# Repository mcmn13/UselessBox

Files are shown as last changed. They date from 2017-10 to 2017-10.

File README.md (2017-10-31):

# UselessBox
Another Useless Box
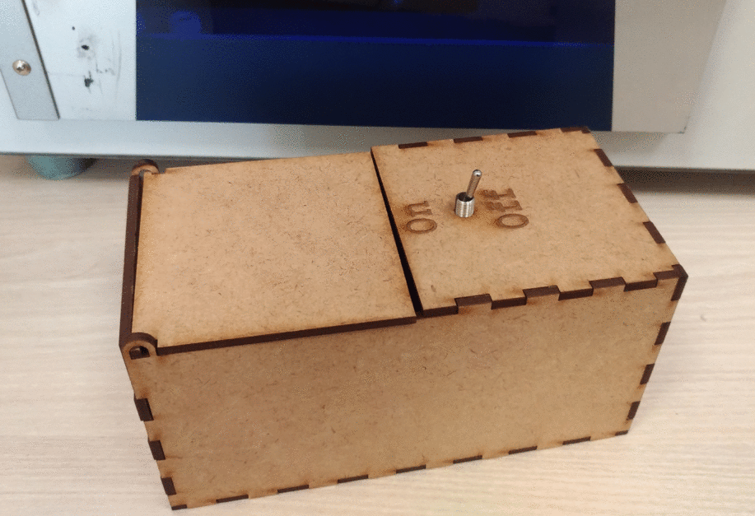
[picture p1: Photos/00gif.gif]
Useless Box en action Useless Box en Action


---

Dans le cadre de notre stage, nous avions pour exercice de mettre en place un atelier de médiation numérique à base de bidouillage Arduino.
Mon choix s'est tourné vers la création d'une "Useless Box" [lien wikipédia](https://fr.wikipedia.org/wiki/Machine_inutile).
Lors de mes recherches, je n'ai pas été satisfait des trouvailles et ai donc mixé différentes sources/projets afin de créer une "Useless Box" compact et simpliste.
La boite est potentiellement améliorable (ajout d'un second servomoteur pour gérer l'ouverture de la trappe, ajout d'un jeu de lumière par LED, ajout de capteur de présence/radar et d'élément de déplacement, mise en place d'un code avec plusieurs scénarios, etc...)
Par manque de temps, je vous livre ici les plans et la documentation nécessaire à l'élaboration d'une useless box basique, libre à vous de lui ajouter d'autres fonctions ;)

PS : sur mon modèle de présentation, il n'y à pas d'interrupteur de mise sous-tension. Il faut alors débrancher/rebrancher manuellement le port VIN pour l'éteindre complétement et préserver la batterie.
N'oubliez pas d'éditer le fichier SVG pour y inclure une fente à la taille de votre interrupteur.

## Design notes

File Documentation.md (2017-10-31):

# Documentation : création d'une Useless Box 
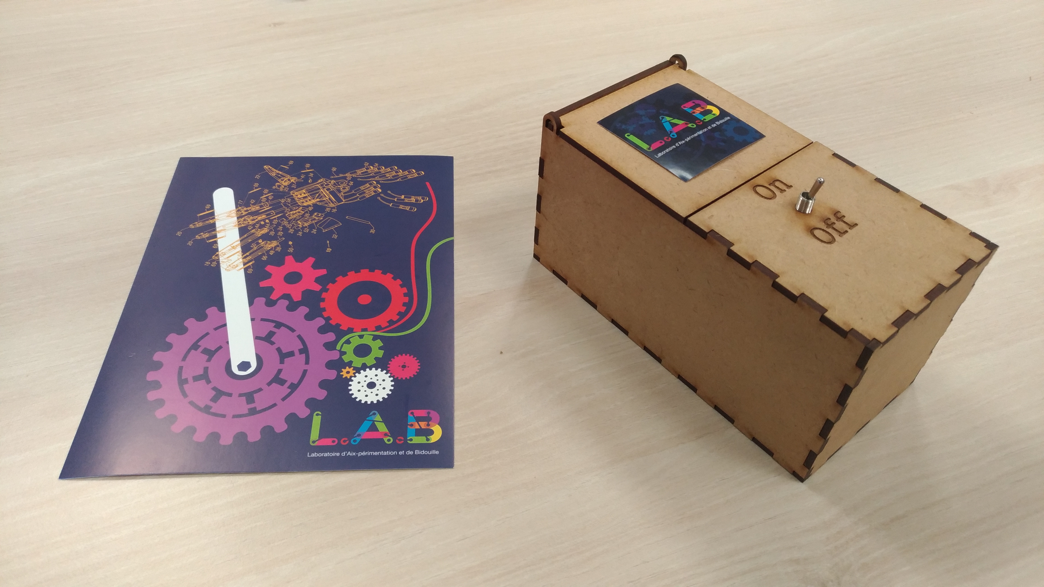
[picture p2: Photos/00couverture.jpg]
Useless Box

# Présentation et objectif pédagogique

Création d'une Useless Box en bois à base d'Arduino.

Objectif pédagogique : 	

- Découvrir les principes de l'électronique
- Savoir utiliser des outils d'électronique dans le respect des règles de sécurité
---

# Pré-requis
## Matériel (total de 42,83€)
- 1 Arduino Uno 21€ ([RS-Composant](http://fr.rs-online.com/web/p/kits-de-developpement-pour-processeurs-et-microcontroleurs/7697409/))
- 1 Servomoteur 12,27€ ([RS-Composant](http://fr.rs-online.com/web/p/servomoteurs/7813058/))
- 1 Bouton Toggle Switch 1,86€ ([RS-Composant](http://fr.rs-online.com/web/p/interrupteurs-a-levier/4480911/))
- 1 Résistance 320 omh
- 1 Connecteur 9V 1,68€ ([ebay](http://www.ebay.fr/itm/1-2-3-4-6-8-x-AA-AAA-23A-9V-Battery-Holder-Snap-On-Connector-Enclosed-Box-Switch/180814661762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))
- 6 Piles AAA 2,96€ les 12 ([RS-Composant](http://fr.rs-online.com/web/p/piles-aaa/7442209/))
- Fils électriques isolés 1,20€ les 65 ([ebay](http://www.ebay.fr/itm/65pcs-Male-to-Male-Flexible-Solderless-Breadboard-Jumper-Cable-Wires-For-Arduino/301227825820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))
- 1 autre bouton toggle switch pour faire la mise sous-tension 1,86€([RS-Composant](http://fr.rs-online.com/web/p/interrupteurs-a-levier/4480911/))
---

## Matériaux
- Planche de Bois 325x250x3mm
- Fil d'étain

## Outils
- Découpeuse laser
- Fer à souder
- Pistolet à colle
- Colle type super glue
- Cable USB PC/Arduino

## Logiciel
- Arduino
- Inkscape
- JobControl (découpeuse laser)

# Création d'une Useless Box

## Etape 1 : Préparation de la boite
1. Munissez-vous d'une plaque de bois 325x300mm d'épaisseur 3mm
2. Préparez la découpeuse laser puis, lancer la découpe à l'aide du fichier ([Plan de coupe](/Ressources/UselessBox_plan-modifié.svg/))
3. Assemblez et collez (super glue ou pistolet-à-colle) la base à ainsi que le côté bas et droit de la boite
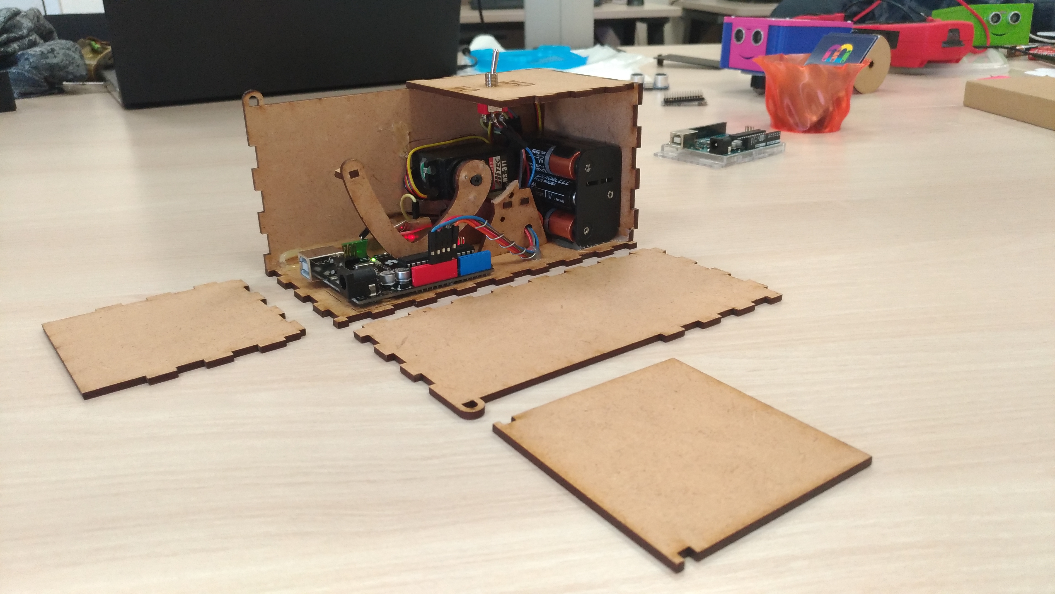
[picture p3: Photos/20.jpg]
Useless Box en assemblage

4. Ne collez pas le couvercle, nous le fixerons après avoir soudé l'interrupteur  :smile:

Nous allons maintenant passer au montage la partie éléctronique

---

## Etape 2 : Montage et préparation de l'Arduino
Référez vous au Fritzing "Useless Box"
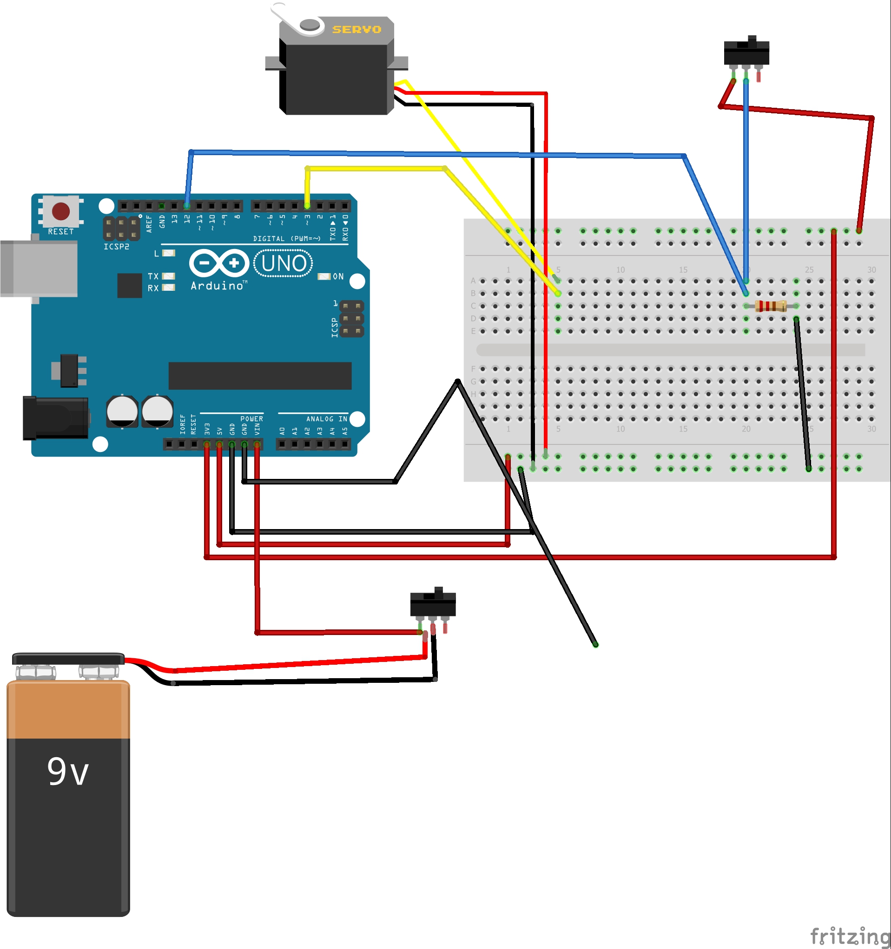
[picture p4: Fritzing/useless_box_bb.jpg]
Fritzing


Les composants à souder : 	
- Connecteur 9V
- Servomoteur
- Résistance
- Boutons toggle switch

**N'oubliez pas de téléverser et tester votre circuit avant de passer à l'assemblage !**

---

## Etape 3 :Assemblage du circuit dans la boite

- Placez l'interrupteur à son emplacement prévu sur la boite.
- Vérifiez le sens "on-off" de l'interrupteur ; Le servomoteur doit s'activer de l'activation (off) jusqu'à la désactivation (off)
- Une fois le sens du bouton toggle switch vérifié, fixez-le à l'aide de super glue
- Avec le pistolet-à-colle, fixez l'adaptateur 9V. N'oubliez pas d'inclure les piles !
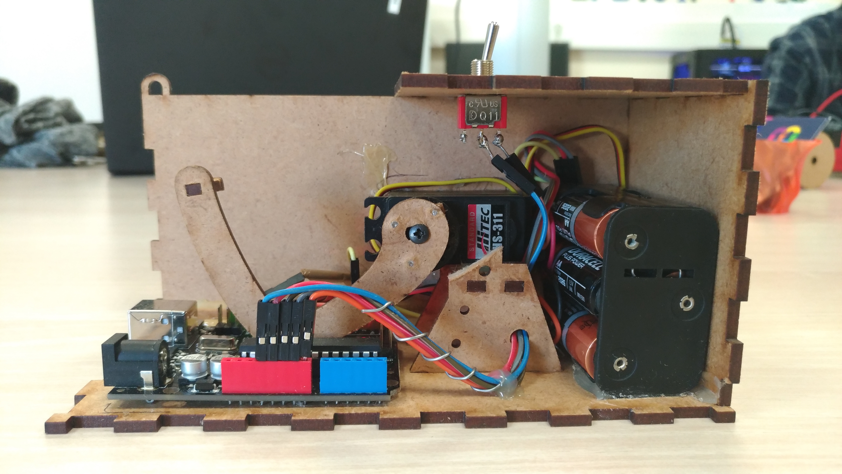
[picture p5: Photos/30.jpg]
Vue de face

- Pour positionner correction le servomoteur, faite un essai avant de le fixer
- Fixez le "Finger" (partie en bois qui vient appuyer l'interrupteur) sur le servomoteur
- Fixez le support en bois sur la base de la boite à l'aide de super glue
- Fixez le servomoteur en le collant sur son support et contre la paroi
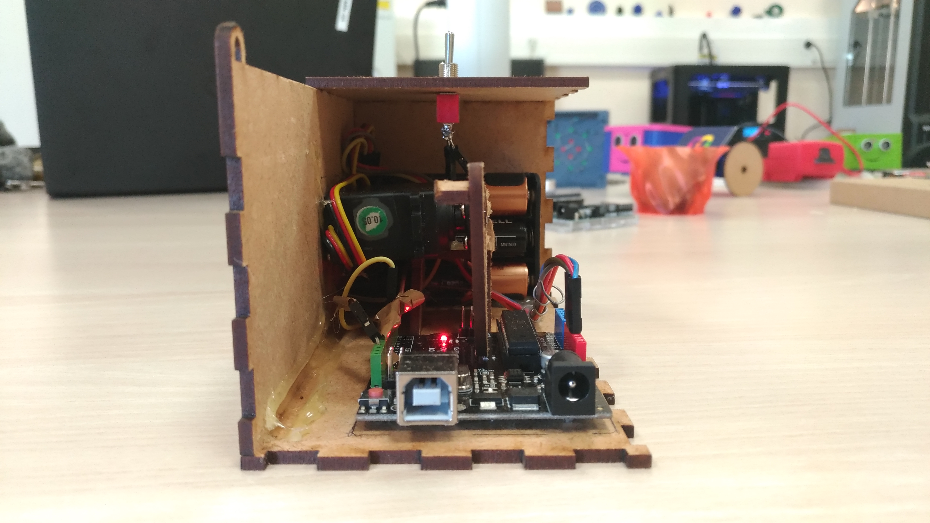
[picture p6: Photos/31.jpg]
Vue de côté

- Fixez l'Arduino sur la base de la carte à l'aide du pistolet-à-colle
- Insérez et fixez l'interrupteur de mise sous-tension à son emplacement prévu (tranche de la boite)
- Fixez le couvercle contenant l'interrupteur à la boite

Je vous conseil de ne pas fixer les 2 autres côtés : l'un permettant l'accès aux piles pour un changement, l'autre permettant l'accès au port USB de l'Arduino.

---
# Pour aller plus loin

N'hésitez pas à rajouter une LED, un second servomoteur, améliorer le code (mise en place de scénario), un capteur de proximité, des roues, etc...

---
# Bibliographie
[Plan de coupe initiale par le FabLab de Leuven](https://fablab-leuven.be/?q=node/1648)

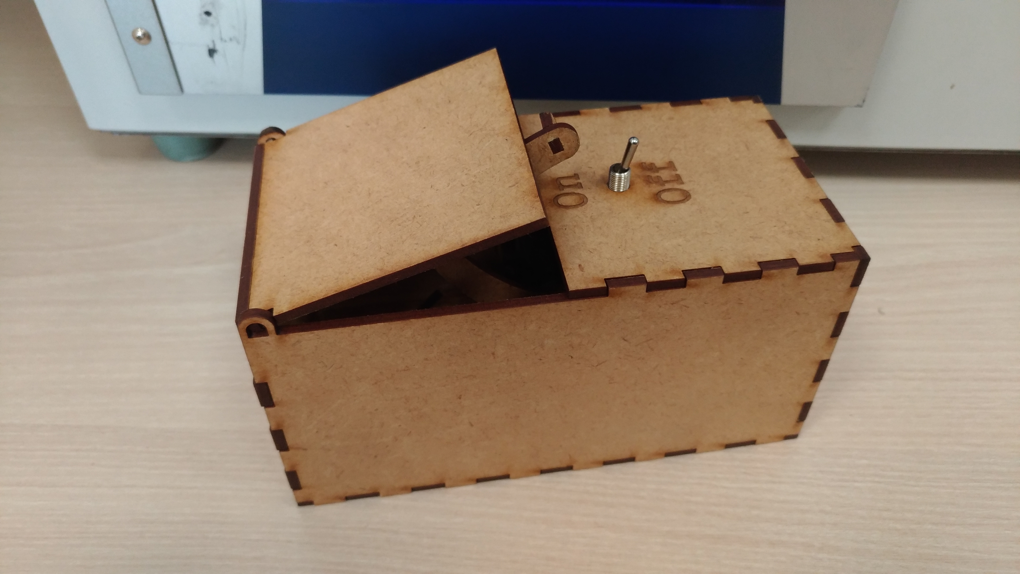
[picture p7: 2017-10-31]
Photos/gif/v2/P_20171027_152757_vHDR_On.jpg

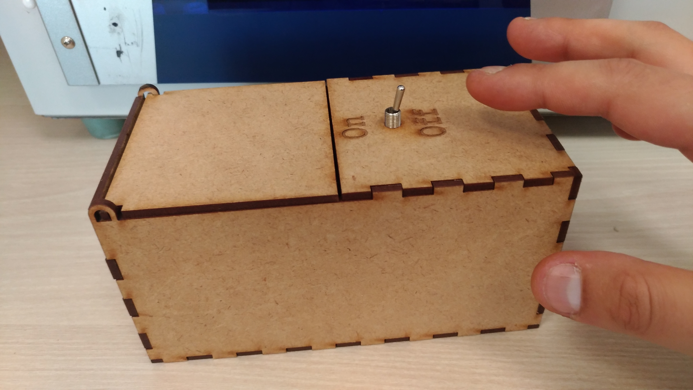
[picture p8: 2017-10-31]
Photos/gif/v2/P_20171027_152837_vHDR_On.jpg

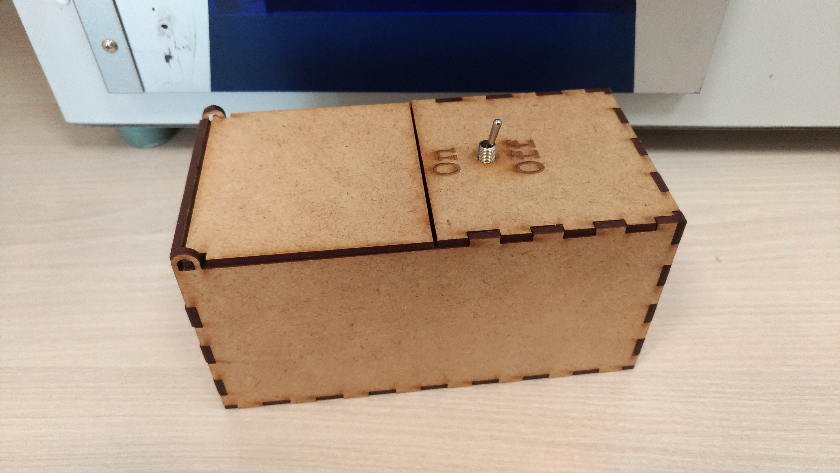
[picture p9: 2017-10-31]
Photos/gif/v2/P_20171027_152811_vHDR_On.jpg

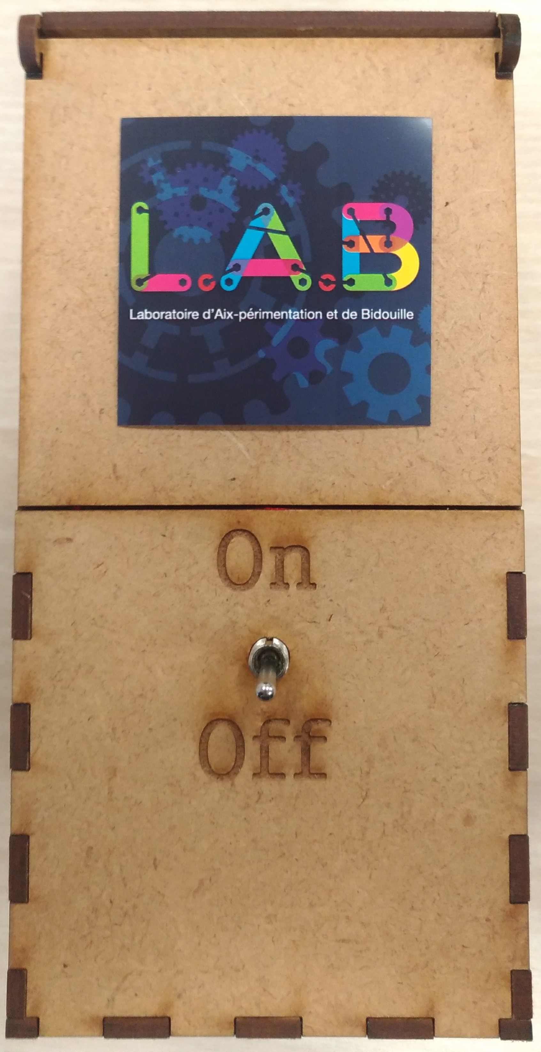
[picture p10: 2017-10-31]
Photos/01box-presentation.jpg

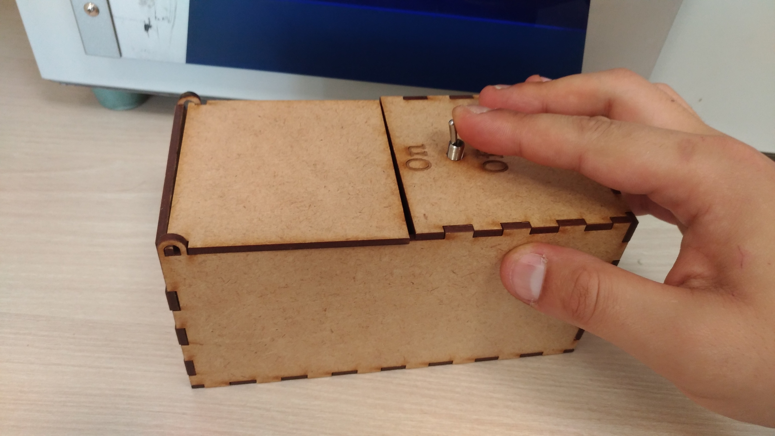
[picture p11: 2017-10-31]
Photos/gif/v2/P_20171027_152726_vHDR_On.jpg

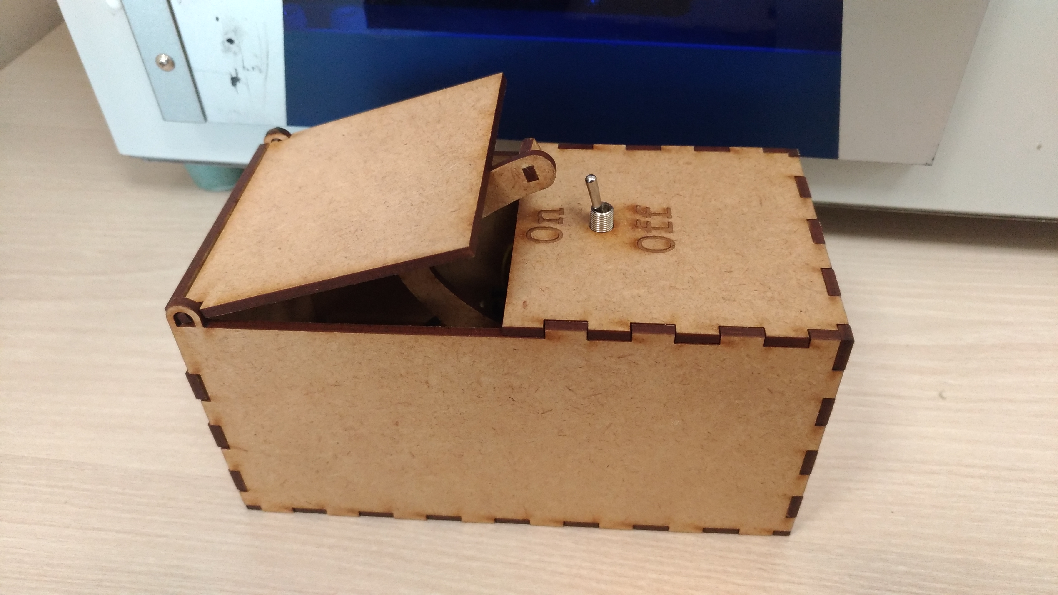
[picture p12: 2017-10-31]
Photos/gif/v2/P_20171027_152910_vHDR_On.jpg

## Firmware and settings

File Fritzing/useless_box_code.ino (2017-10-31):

// Useless Box v1.0
//
// Kai Laborenz 2017
//
// original by BARRAGAN <http://barraganstudio.com>
// This example code is in the public domain.

// include library to operate servos
#include <Servo.h>

// const and variables definitions
const int  buttonPin = 2;
int buttonState = 0;

Servo myservo;        // create servo object to control a servo
                      // a maximum of eight servo objects can be created
int pos;              // variable to store the servo position
long timeDelay;       // variable to store random delay times for servo operation
int counter = 0;        // counter for counting the switch uses
int counterSwitch = 0;

void setup()
{
  pinMode(buttonPin, INPUT);
  myservo.attach(9);    // attaches servo on pin 9 to the servo object

  Serial.begin(9600); // initialize serial communication at 9600 bits per second:
  
}

void loop()
{
  timeDelay = 0;
  buttonState = digitalRead(buttonPin);  


       if (buttonState == HIGH) {  // not switched
                                  
         if (counterSwitch == 0) {                      
           counter = counter + 1;    // advance counter
           counterSwitch = 1;    
           Serial.println(counter);
           }
      
         for(pos = myservo.read(); pos >=20; pos -= 1) {                                     
           myservo.write(pos);     
           }
        }
        else {                    // switched
        
          // if (counter % 2 == 0) { timeDelay = 50; } // every second round goes slower
          
          for(pos = myservo.read(); pos <=90; pos += 1) {                    
            myservo.write(pos);                 
            delay(timeDelay);   
            }
            counterSwitch = 0;
        }
        
}                                 // end main loop

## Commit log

2017-10-31 Importation de la documentation initiale
    [useless_box.fzz]
2017-10-31 Maj documentation + ajout plan de découpe
2017-10-31 Correction de la doc
